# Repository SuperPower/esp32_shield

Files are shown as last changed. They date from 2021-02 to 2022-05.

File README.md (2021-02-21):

# SuperPower
Here you should find the best power supplies for your low-power projects. Because of different requirements for an Raspberry Pi and micro-controllers like the ESP32 we split the project into two boards, one for the Raspberry Pi (SuperPower-Rpi) and one for micro-controllers (SuperPower-uC) with low power.

##### [SuperPower-Rpi](/SuperPower-RPi/) for Raspberry Pi

##### [SuperPower-uC](/SuperPower-uC/) for micro-controllers and low-power devices

## Licence

All hardware designs and products you can find in this repository is licensed under [CERN Open Hardware Licence Version 2 - Weakly Reciprocal](/LICENCE.txt)

## Relevant links

[Discord Channel](https://discord.gg/dCr86Hk)  

[Google Drive Project Files](https://drive.google.com/drive/folders/1lCirijHUkISdUYBIRblkILHM6fstifWS)

Video (https://www.youtube.com/watch?v=-SJbdPvgQnE "Video")

[GitHub Project](https://github.com/SensorsIot/SuperPower)

[Documentation Website](https://superpower.github.io/)

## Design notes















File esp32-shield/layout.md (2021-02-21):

#### Top Layer



#### Bottom Layer



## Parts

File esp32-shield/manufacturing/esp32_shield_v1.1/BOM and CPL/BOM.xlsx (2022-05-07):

Qty | References | Value | Footprint | DNP | LCSC
5 | C5, C6, C19, C20, C21 | 1µF | C_0603_1608Metric |  | C15849
1 | C26 | DNP/1µF | C_0603_1608Metric | DNP
4 | C1, C2, C3, C4 | 22µF | C_0805_2012Metric |  | C45783
4 | R8, R9, R18, R20 | 10k | R_0603_1608Metric_Pad1.05x0.95mm_HandSolder |  | C25804
1 | R23 | DNP/10k | R_0603_1608Metric_Pad1.05x0.95mm_HandSolder | DNP
1 | R24 | 100R | R_0603_1608Metric_Pad1.05x0.95mm_HandSolder |  | C22775
1 | D1 | B5819W | D_SOD-123 |  | C8598
1 | D5 | LED | LED_0603_1608Metric_Pad1.05x0.95mm_HandSolder |  | C72041
1 | D2 | WS2812B | LED_WS2812B_PLCC4_5.0x5.0mm_P3.2mm |  | C2761795
1 | U13 | ESP32-WROOM32 | ESP32-WROOM-32 |  | C701342
1 | U14 | DNP/W25Q32JVSS | SOIC-8_5.23x5.23mm_P1.27mm | DNP
1 | U5 | CH340C | SOP-16_4.55x10.3mm_P1.27mm |  | C84681
1 | U6 | AMS1117-3.3 | SOT-223-3_TabPin2 |  | C6186
1 | U4 | SN74LV1T34DBV | SOT-23-5 |  | C100024
1 | SW1 | SKRKAEE020 | SW_Push_SPST_NO_Alps_SKRK |  | C115357
2 | Q3, Q4 | S8050 | SOT-23_Handsoldering |  | C2146
1 | J9 | DNP/MCU board | PinHeader_1x13_P2.54mm_Vertical | DNP
2 | J5, J6 | DNP/Conn_01x14_Female | PinSocket_1x14_P2.54mm_Vertical | DNP

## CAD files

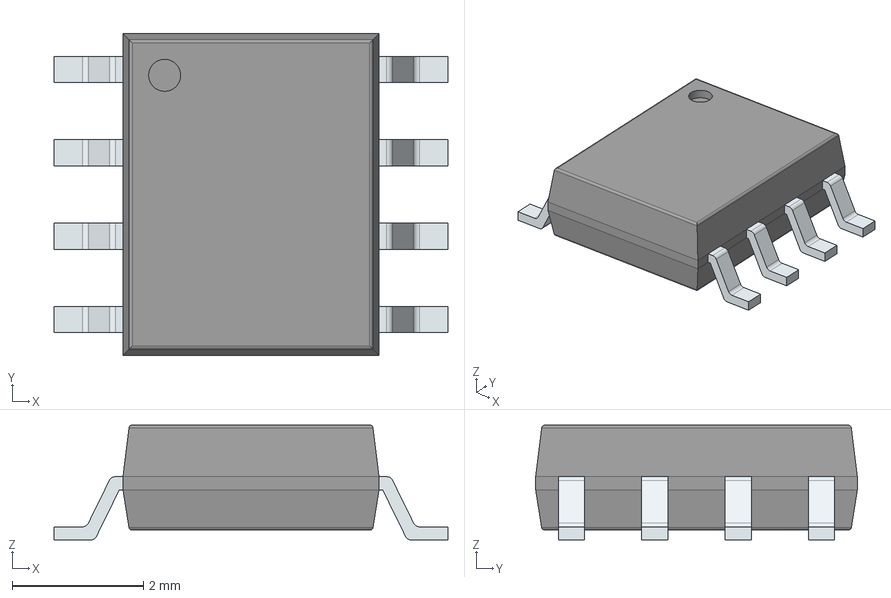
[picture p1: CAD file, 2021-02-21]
components/DMP3028LSD/DMP3028LSD-13.stp
6.00 x 4.90 x 1.75 mm
PinsArrayLR

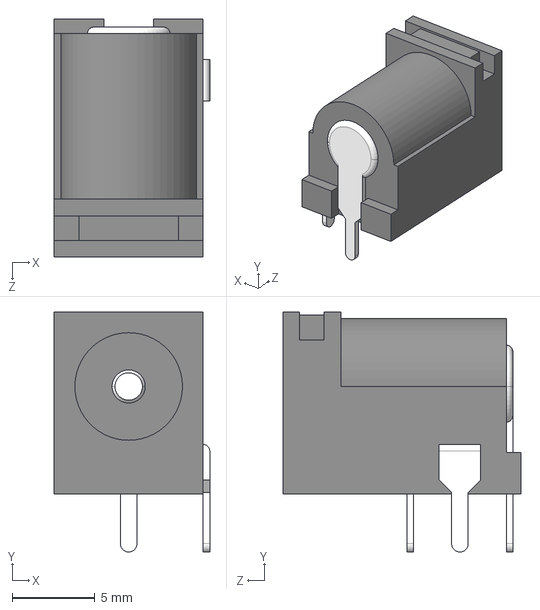
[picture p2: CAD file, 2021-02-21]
components/PJ-102AH--3DModel-STEP-56544.STEP
9.40 x 14.5 x 14.4 mm

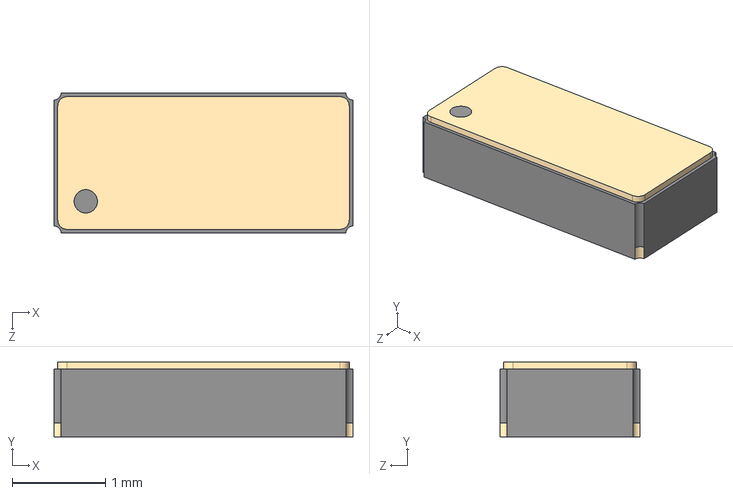
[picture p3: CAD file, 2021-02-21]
components/RV-3028-C7/RV-3028-C7.STEP
3.20 x 0.8 x 1.50 mm

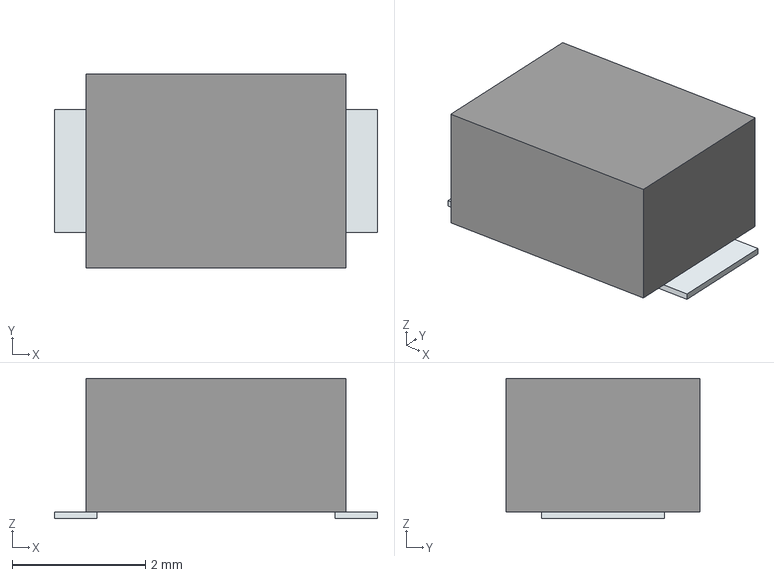
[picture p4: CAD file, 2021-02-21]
components/SKRKAEE020/SKRKAEE020.stp
4.84 x 2.90 x 2.10 mm
Pins

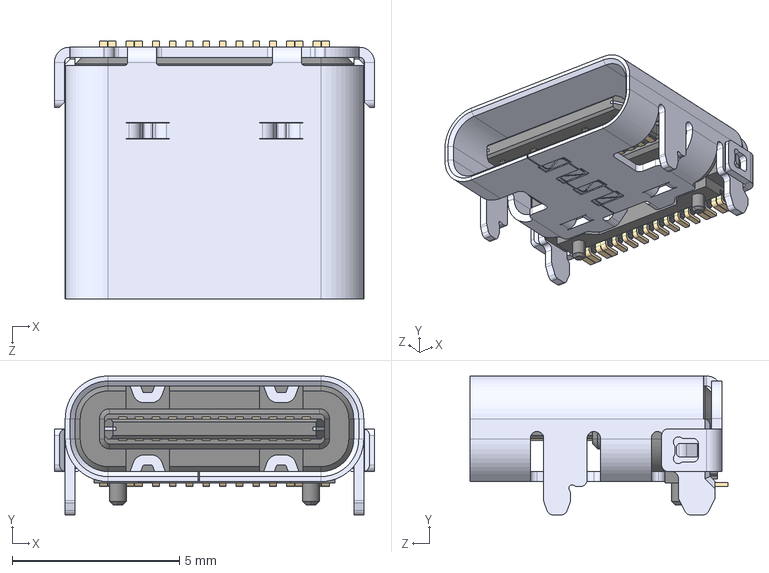
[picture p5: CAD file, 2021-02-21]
components/USB-C/USB4105.STEP
9.58 x 4.16 x 7.71 mm

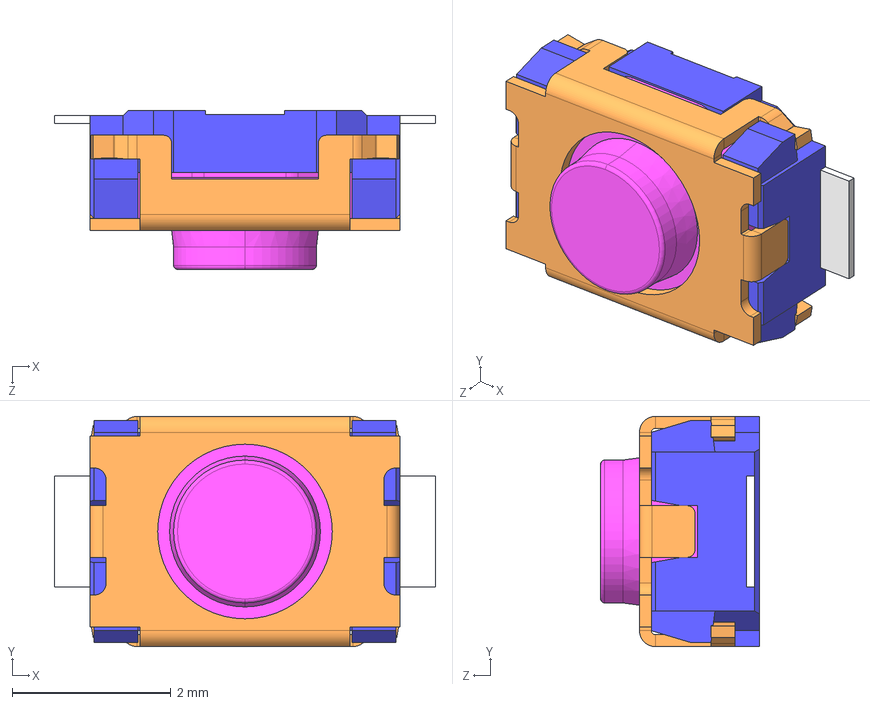
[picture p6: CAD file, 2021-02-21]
components/SKRKAEE020/SKRKAE.STEP
4.80 x 2.90 x 2.00 mm

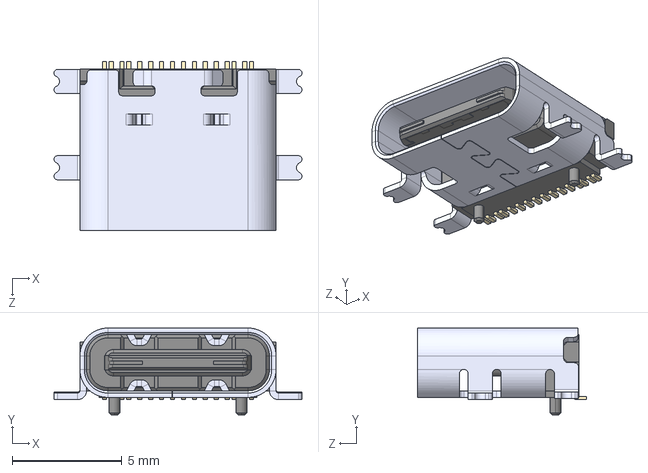
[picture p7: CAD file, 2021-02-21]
components/USB-C/USB4110-GF-A--3DModel-STEP-56544.STEP
11.3 x 3.96 x 7.68 mm

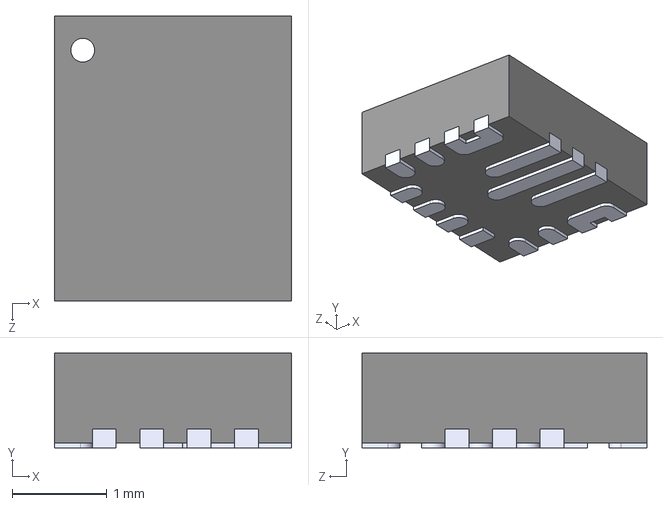
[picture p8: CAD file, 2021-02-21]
components/TPS63070RNM/TPS63070RNMT.STEP
2.50 x 1.00 x 3.00 mm

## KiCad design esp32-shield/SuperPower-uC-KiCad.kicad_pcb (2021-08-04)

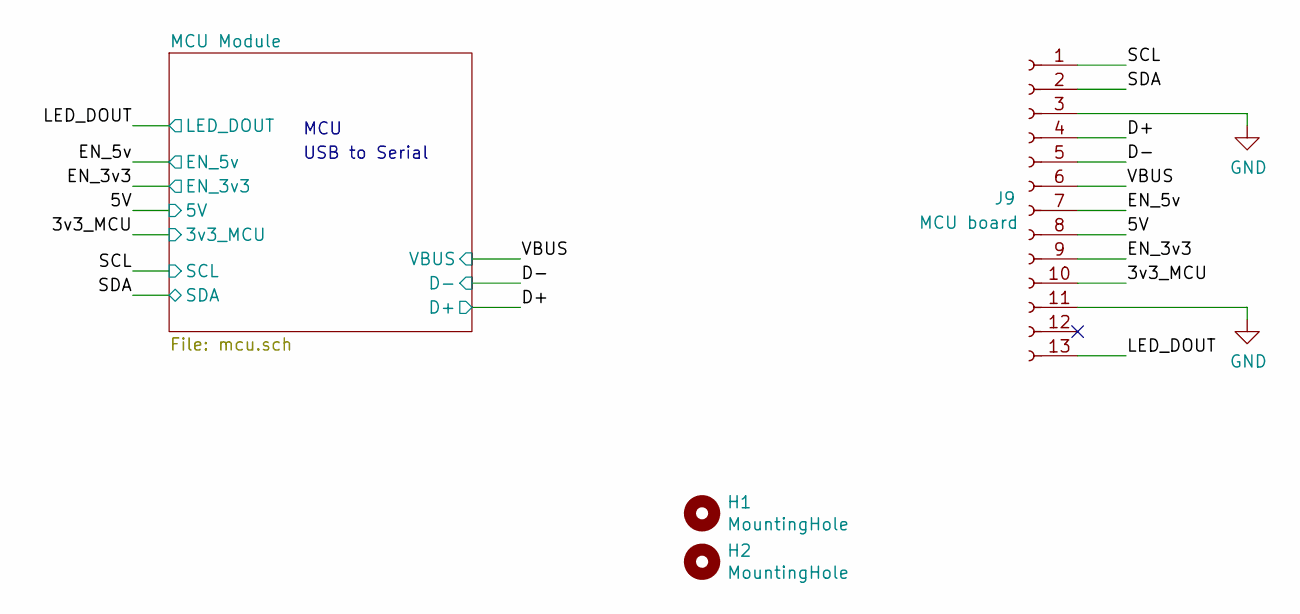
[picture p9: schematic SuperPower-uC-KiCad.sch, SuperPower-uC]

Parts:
H1, H2: MountingHole; MountingHole_2.7mm_M2.5_ISO7380
J9: MCU board; PinHeader_1x13_P2.54mm_Vertical

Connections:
/3v3_MCU: J9.10; also elsewhere on the board
/5V: J9.8; also elsewhere on the board
/D+: J9.4; also elsewhere on the board
/D-: J9.5; also elsewhere on the board
/EN_3v3: J9.9; also elsewhere on the board
/EN_5v: J9.7; also elsewhere on the board
/LED_DOUT: J9.13; also elsewhere on the board
/SCL: J9.1; also elsewhere on the board
/SDA: J9.2; also elsewhere on the board
/VBUS: J9.6; also elsewhere on the board
GND: J9.3, J9.11; also elsewhere on the board

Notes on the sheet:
MCU
USB to Serial

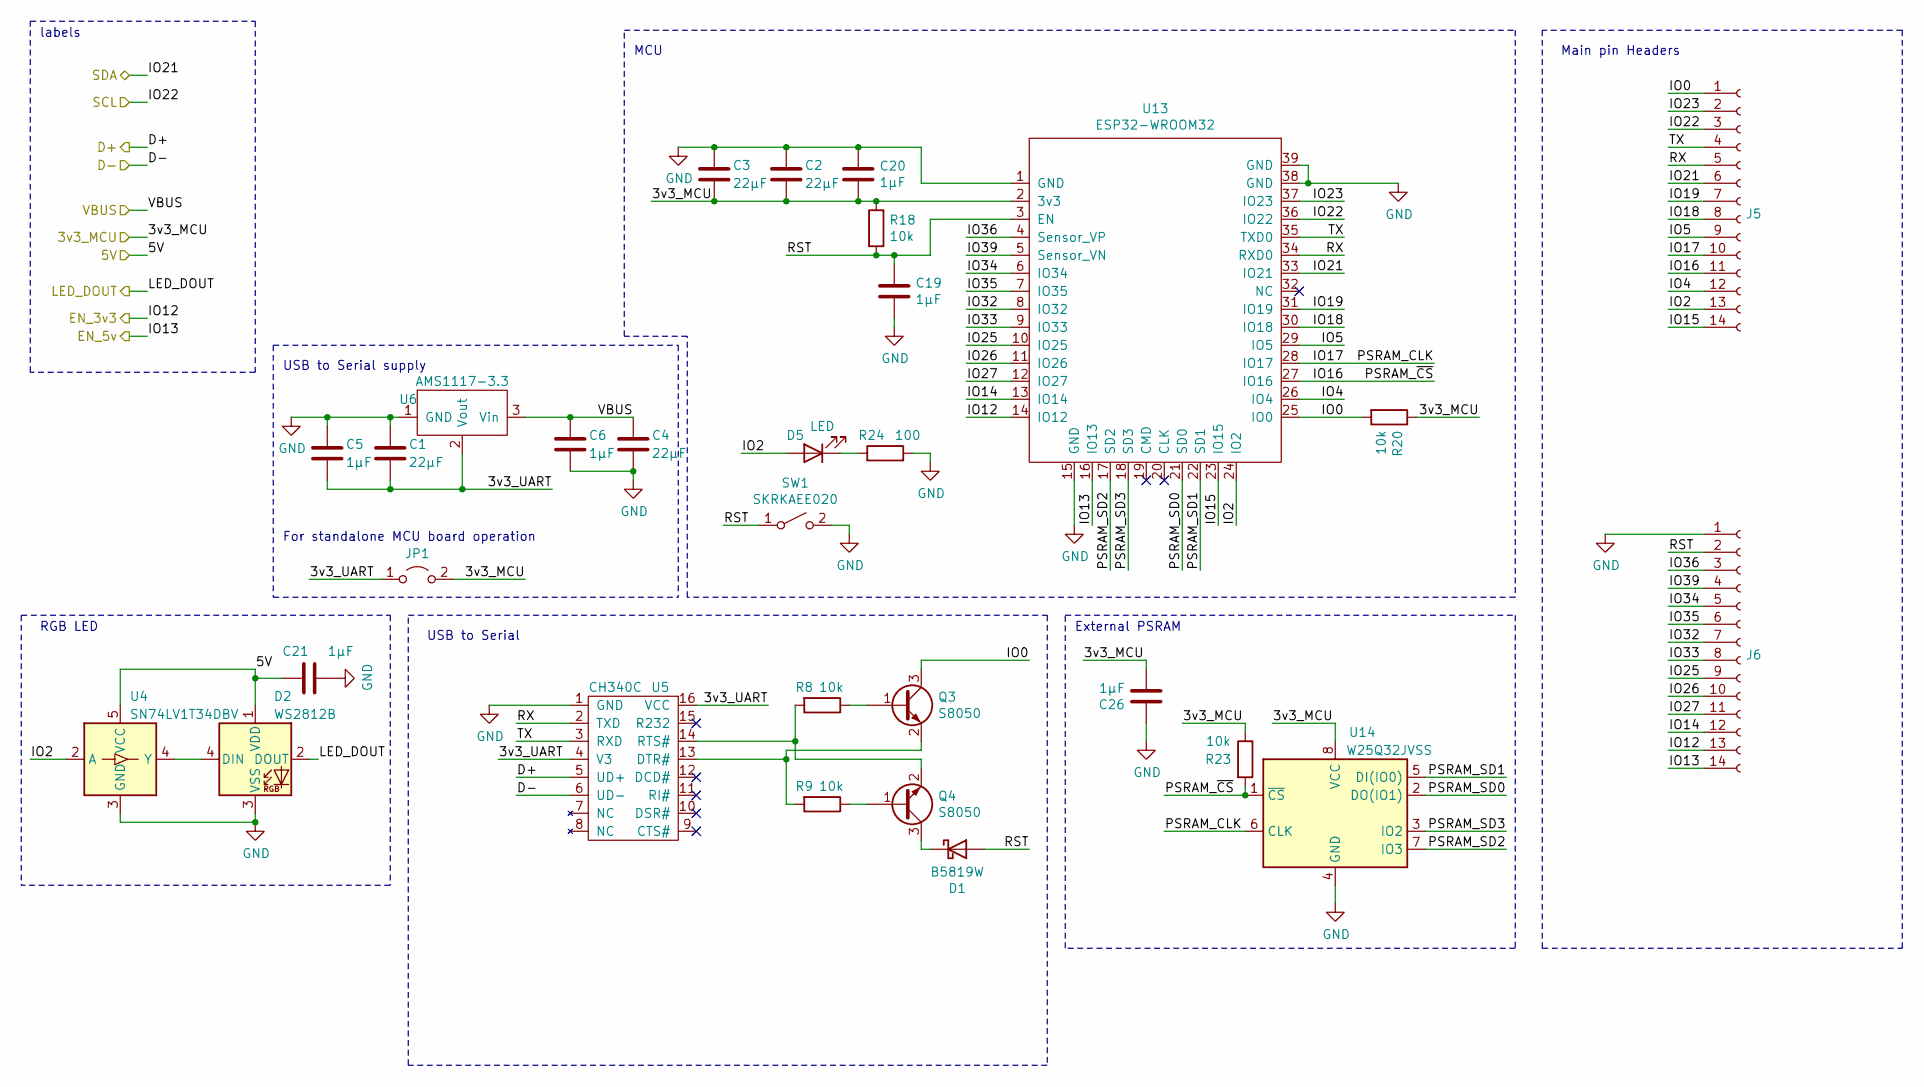
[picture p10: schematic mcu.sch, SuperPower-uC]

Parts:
C1, C2, C3, C4: 22µF; C_0805_2012Metric; LCSC C45783
C5, C6, C19, C20, C21, C26: 1µF; C_0603_1608Metric; LCSC C15849
D1: B5819W; D_SOD-123; LCSC C8598
D2: WS2812B; LED_WS2812B_PLCC4_5.0x5.0mm_P3.2mm; LCSC C114586
D5: LED; LED_0603_1608Metric_Pad1.05x0.95mm_HandSolder; LCSC C72041
J5, J6: Conn_01x14_Female; PinSocket_1x14_P2.54mm_Vertical
JP1: Jumper_2_Open; SolderJumper-2_P1.3mm_Open_Pad1.0x1.5mm
Q3, Q4: S8050; SOT-23_Handsoldering; LCSC C2146
R8, R9, R18, R20, R23: 10k; R_0603_1608Metric_Pad1.05x0.95mm_HandSolder; LCSC C25804
R24: 100; R_0603_1608Metric_Pad1.05x0.95mm_HandSolder; LCSC C22775
SW1: SKRKAEE020; SW_Push_SPST_NO_Alps_SKRK; LCSC C115357
U4: SN74LV1T34DBV; SOT-23-5; LCSC C100024
U5: CH340C; SOP-16_4.55x10.3mm_P1.27mm; LCSC C84681
U6: AMS1117-3.3; SOT-223-3_TabPin2; LCSC C6186
U13: ESP32-WROOM32; ESP32-WROOM-32; LCSC C82899
U14: W25Q32JVSS; SOIC-8_5.23x5.23mm_P1.27mm; LCSC C25804

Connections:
/3v3_MCU: C2.2, C3.2, C20.2, C26.2, JP1.2 (B), R18.1, R20.1, R23.1, U13.2 (3v3), U14.8 (VCC); also elsewhere on the board
/5V: C21.1, D2.1 (VDD), U4.5 (VCC); also elsewhere on the board
/D+: U5.5 (UD+); also elsewhere on the board
/D-: U5.6 (UD-); also elsewhere on the board
/EN_3v3: J6.13, U13.14 (IO12); also elsewhere on the board
/EN_5v: J6.14, U13.16 (IO13); also elsewhere on the board
/LED_DOUT: D2.2 (DOUT); also elsewhere on the board
/MCU Module/3v3_UART: C1.2, C5.2, JP1.1 (A), U5.4 (V3), U5.16 (VCC), U6.2 (Vout)
/MCU Module/IO0: J5.1, Q3.3 (C), R20.2, U13.25 (IO0)
/MCU Module/IO2: D5.2 (A), J5.13, U4.2 (A), U13.24 (IO2)
/MCU Module/IO4: J5.12, U13.26 (IO4)
/MCU Module/IO5: J5.9, U13.29 (IO5)
/MCU Module/IO14: J6.12, U13.13 (IO14)
/MCU Module/IO15: J5.14, U13.23 (IO15)
/MCU Module/IO16: J5.11, R23.2, U13.27 (IO16), U14.1 (~CS)
/MCU Module/IO17: J5.10, U13.28 (IO17), U14.6 (CLK)
/MCU Module/IO18: J5.8, U13.30 (IO18)
/MCU Module/IO19: J5.7, U13.31 (IO19)
/MCU Module/IO23: J5.2, U13.37 (IO23)
/MCU Module/IO25: J6.9, U13.10 (IO25)
/MCU Module/IO26: J6.10, U13.11 (IO26)
/MCU Module/IO27: J6.11, U13.12 (IO27)
/MCU Module/IO32: J6.7, U13.8 (IO32)
/MCU Module/IO33: J6.8, U13.9 (IO33)
/MCU Module/IO34: J6.5, U13.6 (IO34)
/MCU Module/IO35: J6.6, U13.7 (IO35)
/MCU Module/IO36: J6.3, U13.4 (Sensor_VP)
/MCU Module/IO39: J6.4, U13.5 (Sensor_VN)
/MCU Module/PSRAM_SD0: U13.21 (SD0), U14.2 (DO(IO1))
/MCU Module/PSRAM_SD1: U13.22 (SD1), U14.5 (DI(IO0))
/MCU Module/PSRAM_SD2: U13.17 (SD2), U14.7 (IO3)
/MCU Module/PSRAM_SD3: U13.18 (SD3), U14.3 (IO2)
/MCU Module/RST: C19.1, D1.2 (A), J6.2, R18.2, SW1.1 (A), U13.3 (EN)
/MCU Module/RX: J5.5, U5.2 (TXD), U13.34 (RXD0)
/MCU Module/TX: J5.4, U5.3 (RXD), U13.35 (TXD0)
/SCL: J5.3, U13.36 (IO22); also elsewhere on the board
/SDA: J5.6, U13.33 (IO21); also elsewhere on the board
/VBUS: C4.1, C6.1, U6.3 (Vin); also elsewhere on the board
GND: C1.1, C2.1, C3.1, C4.2, C5.1, C6.2, C19.2, C20.1, C21.2, C26.1, D2.3 (VSS), J6.1, R24.2, SW1.2 (B), U4.3 (GND), U5.1 (GND), U6.1 (GND), U13.1 (GND), U13.15 (GND), U13.38 (GND), U13.39 (GND), U14.4 (GND); also elsewhere on the board
unnamed: D1.1 (K), Q4.3 (C)
unnamed: D2.4 (DIN), U4.4 (Y)
unnamed: D5.1 (K), R24.1
unnamed: Q3.1 (B), R8.1
unnamed: Q3.2 (E), R9.2, U5.13 (DTR#)
unnamed: Q4.1 (B), R9.1
unnamed: Q4.2 (E), R8.2, U5.14 (RTS#)

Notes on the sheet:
MCU
labels
Main pin Headers
USB to Serial supply
USB to Serial
For standalone MCU board operation
External PSRAM
RGB LED

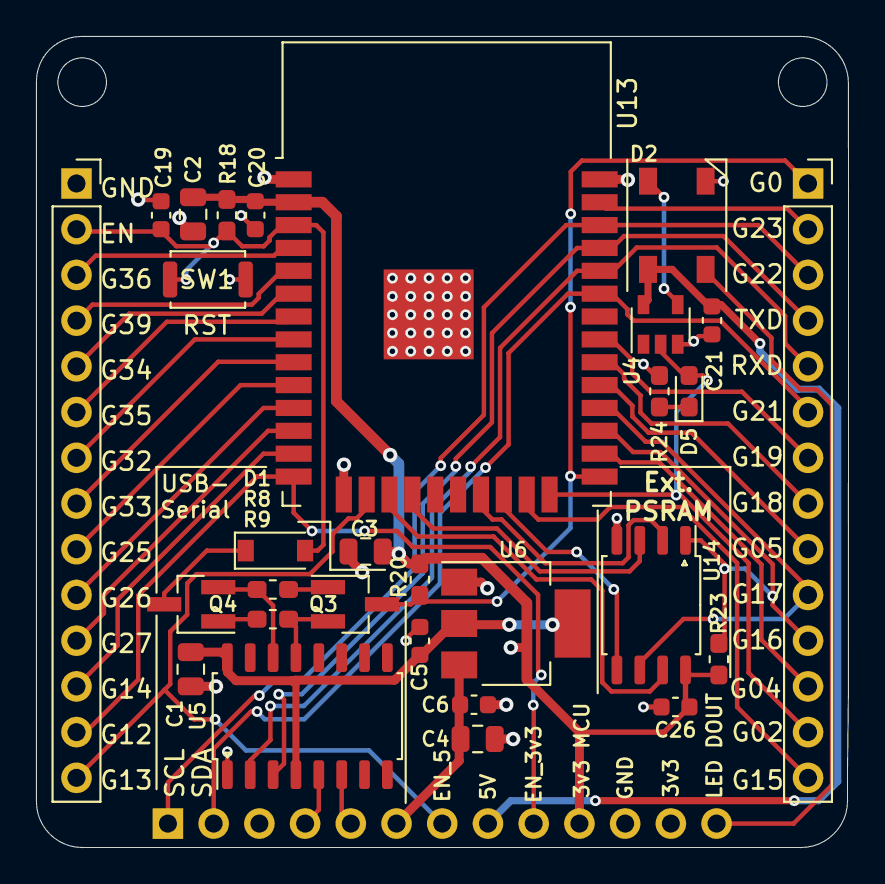
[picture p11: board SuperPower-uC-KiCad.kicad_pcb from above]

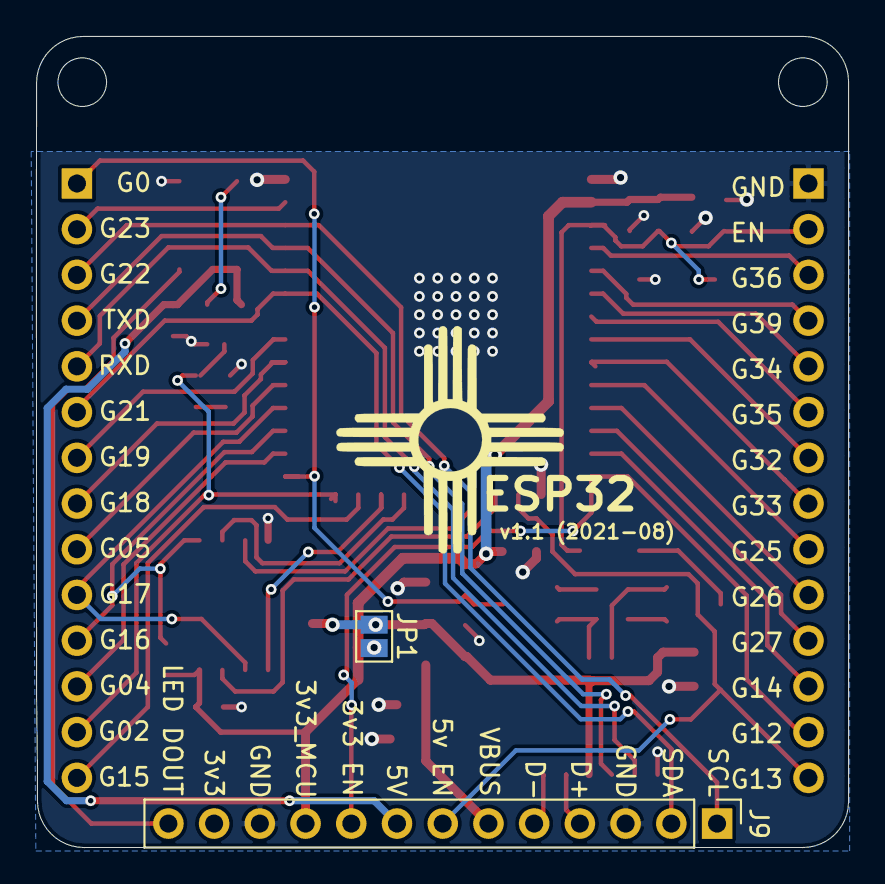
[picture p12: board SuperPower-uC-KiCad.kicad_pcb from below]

Board: 2 copper layers, 45.1 x 45.1 mm, 33 parts (2 on the bottom side), 46 nets.

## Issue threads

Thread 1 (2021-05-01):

prototype findings

Tobi3566, 2021-05-01:
- SK6812 currently powered with 5v does not respond to 3.3V signal (possible but suboptimal solution would be to connect it to 3.3V /3.3V_MCU

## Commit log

2021-02-17 changed naming of usb to serial stuff and added led to mcu board
    [SuperPower-uC-KiCad.kicad_pcb, SuperPower-uC-KiCad.sch, mcu.sch]
2021-02-17 disconnected 5v_EN and 3v3_EN from the pin header on the regulator board
    [SuperPower-uC-KiCad.kicad_pcb, SuperPower-uC-KiCad.sch, rtc_cut_off.sch]
2021-02-21 Moved repo and made it esp32-shield only files
    [BOM.xlsx, DMP3028LSD-13.stp, PJ-102AH--3DModel-STEP-56544.STEP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]
2021-02-22 deleted unused files and renamed net lables
    [SuperPower-uC-KiCad.kicad_pcb, SuperPower-uC-KiCad.sch, battery_protection.sch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]
2021-02-23 added rgbw led, swapped ch340g for ch340c part numers
    also marked crystal and caps as DNP
    [SuperPower-uC-KiCad.kicad_pcb, SuperPower-uC-KiCad.sch, mcu.sch]
2021-03-05 added more input caps & part number for button
    [SuperPower-uC-KiCad.kicad_pcb, mcu.sch]
2021-03-08 fixed drc
    [SuperPower-uC-KiCad.kicad_pcb]
2021-03-08 changed switch value
    [mcu.sch]
2021-04-02 removed led pin 1 marking and added corner on silk
    [SuperPower-uC-KiCad.kicad_pcb]
2021-05-24 swapped button lcsc part number for cheaper alps one
    [mcu.sch]
2021-05-27 swapped led for WS2812 footprint with logic level shifter
    [SuperPower-uC-KiCad.kicad_pcb, SuperPower-uC-KiCad.sch, mcu.sch]
2021-05-27 added more silk labels where there was space
    [SuperPower-uC-KiCad.kicad_pcb]
2021-05-28 updated pcb version number and date
    [SuperPower-uC-KiCad.kicad_pcb]
2021-05-29 RGB led on right side and using pin 2
    [SuperPower-uC-KiCad.kicad_pcb, SuperPower-uC-KiCad.sch, mcu.sch]
2021-05-29 rearranged tracks on left side
    [SuperPower-uC-KiCad.kicad_pcb]
2021-05-30 some minor silk and routing improvements
    [SuperPower-uC-KiCad.kicad_pcb]
2021-06-07 added another 22µ cap to 3v3mcu rail
    [SuperPower-uC-KiCad.kicad_pcb, mcu.sch]
2021-06-22 swapped .1µ caps for 1µ caps
    [mcu.sch]
2021-07-06 changed CH340G to CH340C, deleted crystal footprint and caps, added caps
    [SuperPower-uC-KiCad.kicad_pcb, SuperPower-uC-KiCad.sch, mcu.sch]
2021-07-09 swapped jumper with solderbridge
    [SuperPower-uC-KiCad.kicad_pcb, mcu.sch]
2021-08-02 fixed silk positioning
    [SuperPower-uC-KiCad.kicad_pcb]
2021-08-04 Marked components DNP
    [SuperPower-uC-KiCad.kicad_pcb]
2021-08-04 Created BOM + removed old files
    [BOM.xlsx]
2021-08-04 Generated Gerber files
    [SuperPower-uC-KiCad-B_Cu.gbr, SuperPower-uC-KiCad-B_Mask.gbr, SuperPower-uC-KiCad-B_SilkS.gbr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]
2022-02-03 organized production files and added lcsc part numbers
    [BOM.xlsx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]
2022-04-28 added part numbers and extended ref
    [mcu.sch]
2022-05-07 updated production files
    [BOM.xlsx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]

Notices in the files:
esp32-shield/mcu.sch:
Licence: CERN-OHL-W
